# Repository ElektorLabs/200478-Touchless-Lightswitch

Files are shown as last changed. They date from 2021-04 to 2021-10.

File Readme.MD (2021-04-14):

# 200478 - Touchless Lightswitch

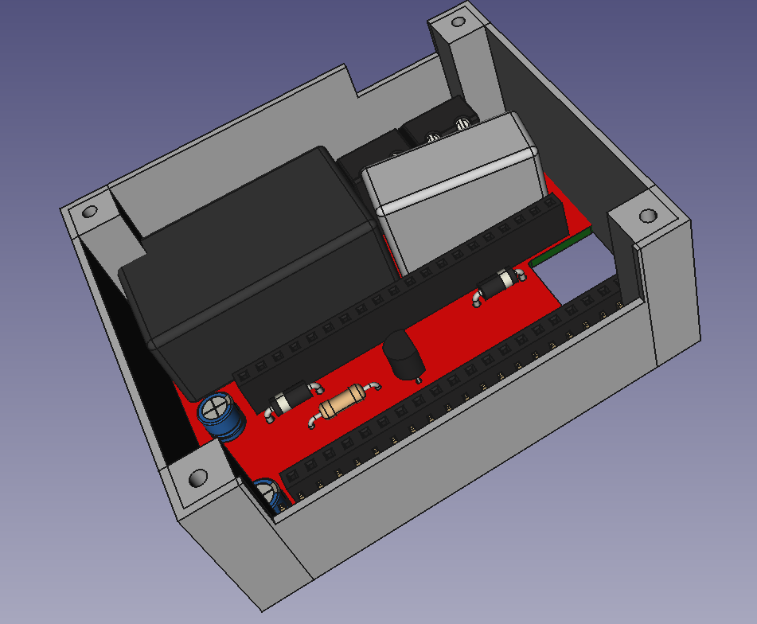
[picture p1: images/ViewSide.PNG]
3D Rendering of enclosure and pcb


## WARNING

This is work in progress and not finished. There may be leathal bugs inside the design. Use at your own risk

## Not working yet
```
- Webpage not included
- Size to large
- Mains supply not safe
```
## Description

This is the prototype of a touchless opperating lightswitch using the MGC3130 from Micorchip and an ESP32 as MCU
Code is done in PlatformIO and dependencys should be loaded automatically. 

A PCB done in KiCad and an Enclosure done in FreeCAD are also included. 

## Firmware installation

```bash
Download the code and import it into PlatformIO
```

## Contributing
Pull requests are welcome. For major changes, please open an issue first to discuss what you would like to change.

## Branches
Be aware that this project may use different branches and check out the one you like to use

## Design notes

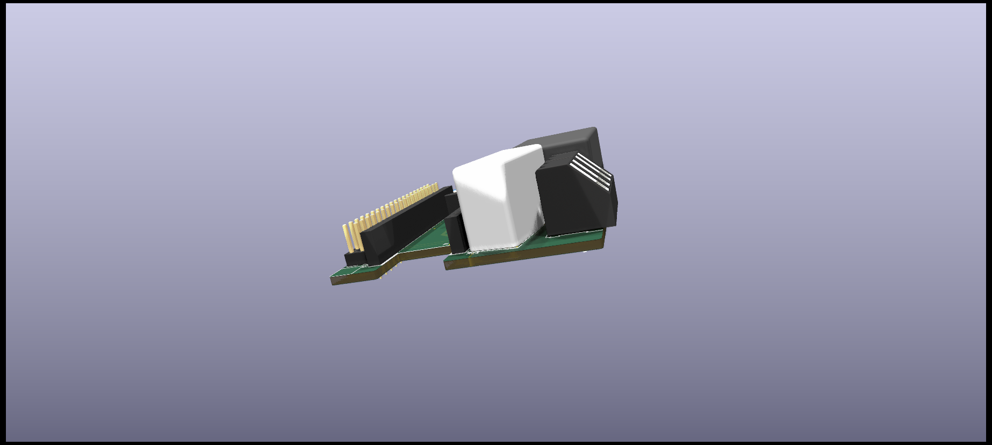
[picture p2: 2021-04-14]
images/TouchlessSwitch_PCB_Small.png

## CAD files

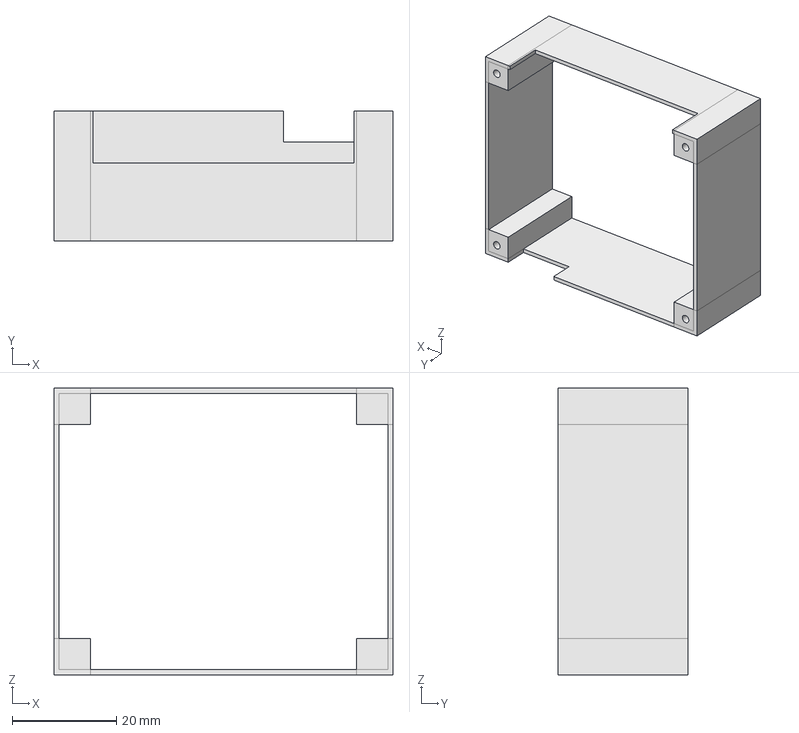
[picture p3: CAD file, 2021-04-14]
hardware/Enclosure/TouchSwitchEnclosure.step
65.0 x 25.0 x 55.0 mm

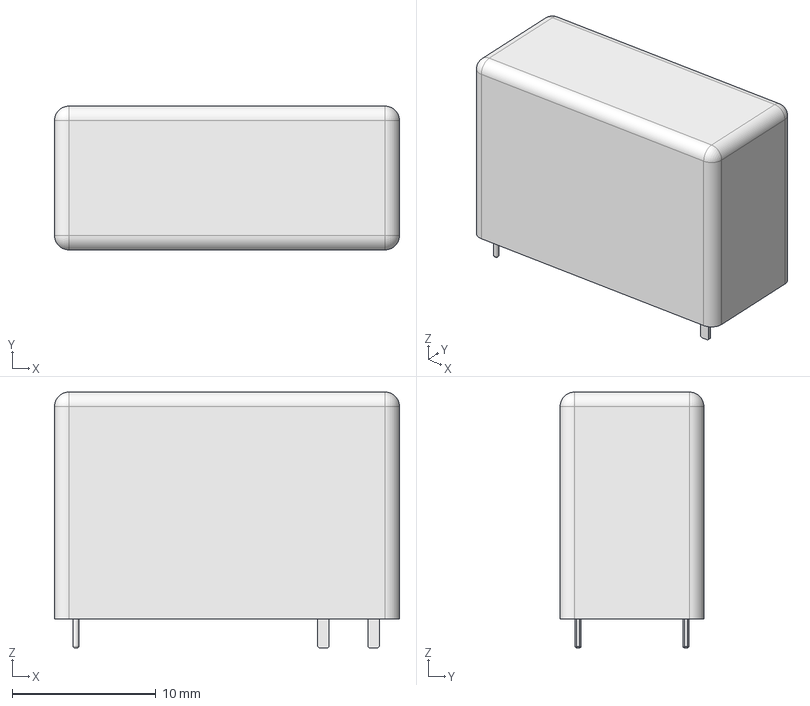
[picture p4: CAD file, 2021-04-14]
hardware/PCB/Touchless Switch/TouchlessSwitch/3D objects/ADW11HL.step
24.0 x 10.0 x 17.8 mm

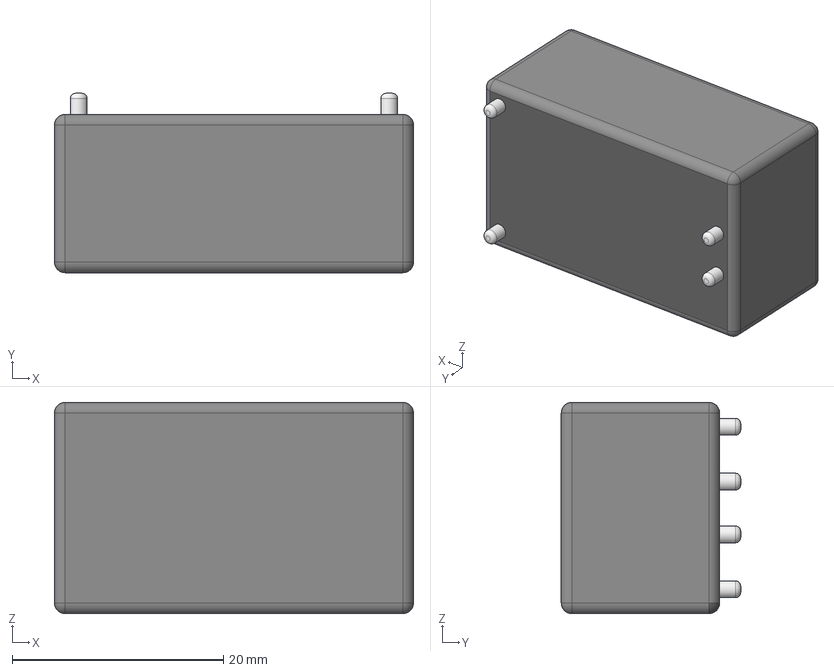
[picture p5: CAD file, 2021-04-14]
hardware/PCB/Touchless Switch/TouchlessSwitch/HKLinkACDC.step
34.0 x 17.0 x 20.0 mm

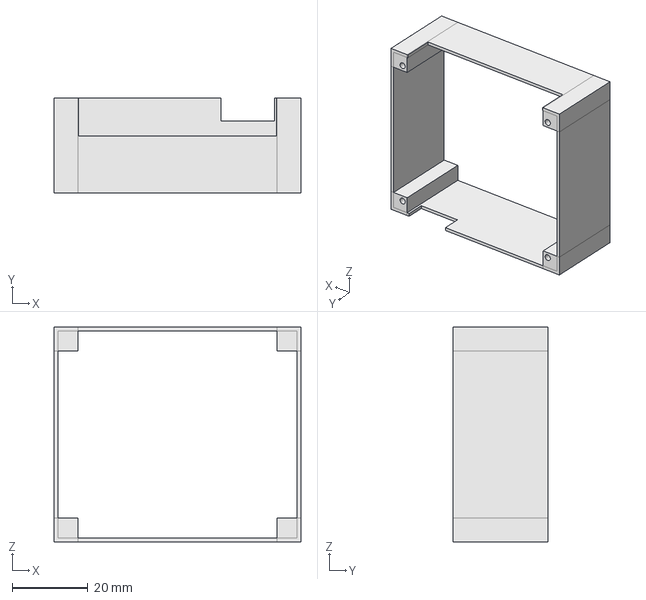
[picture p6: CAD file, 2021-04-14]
hardware/Enclosure/TouchlessTouchSwitch0_9.FCStd
65.0 x 25.0 x 56.5 mm

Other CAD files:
hardware/Enclosure/HiLinkACDC-PM01.FCStd
hardware/Enclosure/Relay_3D.FCStd
hardware/Enclosure/TouchSwitchEnclosure.stl

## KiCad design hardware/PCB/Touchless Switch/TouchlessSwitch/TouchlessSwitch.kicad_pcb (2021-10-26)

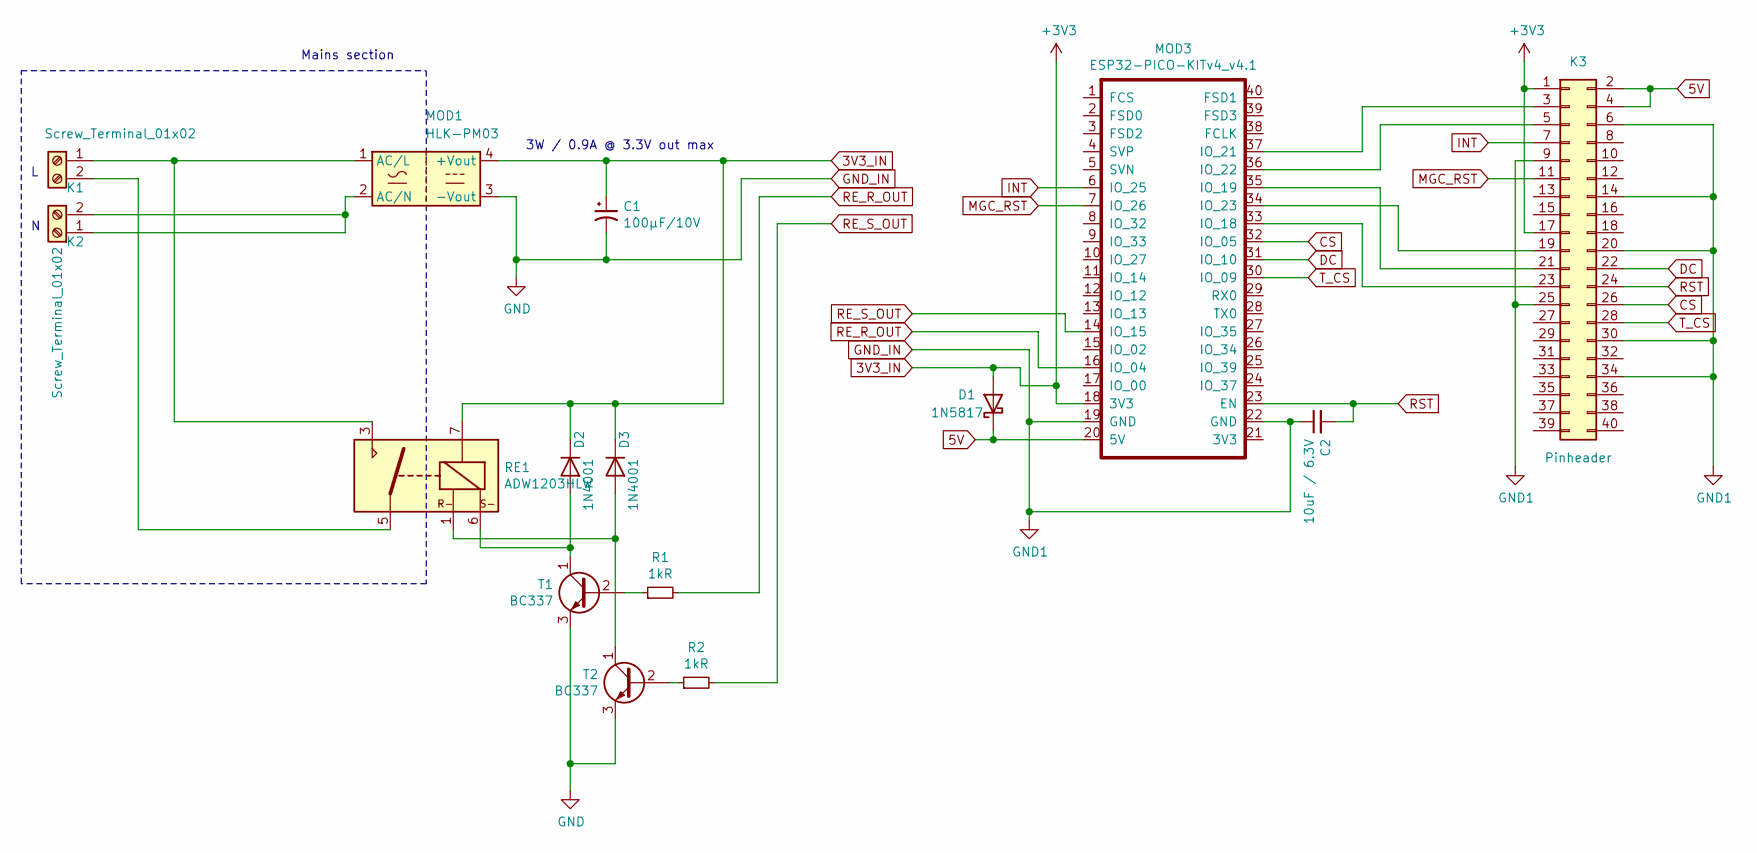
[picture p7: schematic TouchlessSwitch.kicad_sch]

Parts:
C1: 100µF/10V; CP_Radial_D5.0mm_P2.00mm
C2: 10uF / 6.3V; CP_Radial_D5.0mm_P2.00mm
D1: 1N5817; D_DO-41_SOD81_P7.62mm_Horizontal
D2, D3: 1N4001; D_DO-41_SOD81_P7.62mm_Horizontal
K1, K2: Screw_Terminal_01x02; TerminalBlock_Altech_AK300-2_P5.00mm
K3: Pinheader; PinHeader_2x20_P2.54mm_Vertical
MOD1: HLK-PM03; Converter_ACDC_HiLink_HLK-PMxx
MOD3: ESP32-PICO-KITv4_v4.1; DIP-40_W17.78mm_Socket
R1, R2: 1kR; R_Axial_DIN0207_L6.3mm_D2.5mm_P10.16mm_Horizontal
RE1: ADW1203HLW; Relay_1P1T_NO_10x24x18.8mm_Panasonic_ADW11xxxxW_THT
T1, T2: BC337; TO-92_Inline

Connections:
3V3_IN: C1.1, D1.2 (A), D2.1 (K), D3.1 (K), K3.1, K3.17, MOD1.4 (+Vout), MOD3.18 (3V3), RE1.7
5V: D1.1 (K), K3.2, K3.4, MOD3.20 (5V)
CS: K3.26, MOD3.32 (IO_05)
DC: K3.22, MOD3.31 (IO_10)
GND_IN: C1.2, C2.1, K3.6, K3.9, K3.14, K3.20, K3.25, K3.30, K3.34, MOD1.3 (-Vout), MOD3.19 (GND), MOD3.22 (GND), T1.3 (E), T2.3 (E)
INT: K3.7, MOD3.6 (IO_25)
MGC_RST: K3.11, MOD3.7 (IO_26)
unnamed: D2.2 (A), RE1.6, T1.1 (C)
unnamed: D3.2 (A), RE1.1, T2.1 (C)
unnamed: K1.1, MOD1.1 (AC/L), RE1.3
unnamed: K1.2, RE1.5
unnamed: K2.1, K2.2, MOD1.2 (AC/N)
unnamed: K3.3, MOD3.37 (IO_21)
unnamed: K3.5, MOD3.36 (IO_22)
unnamed: K3.19, MOD3.34 (IO_23)
unnamed: K3.21, MOD3.35 (IO_19)
unnamed: K3.23, MOD3.33 (IO_18)
unnamed: R1.1, T1.2 (B)
unnamed: R2.1, T2.2 (B)
RE_R_OUT: MOD3.16 (IO_04), R1.2
RE_S_OUT: MOD3.14 (IO_15), R2.2
RST: C2.2, K3.24, MOD3.23 (EN)
T_CS: K3.28, MOD3.30 (IO_09)

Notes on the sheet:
Mains section
3W / 0.9A @ 3.3V out max

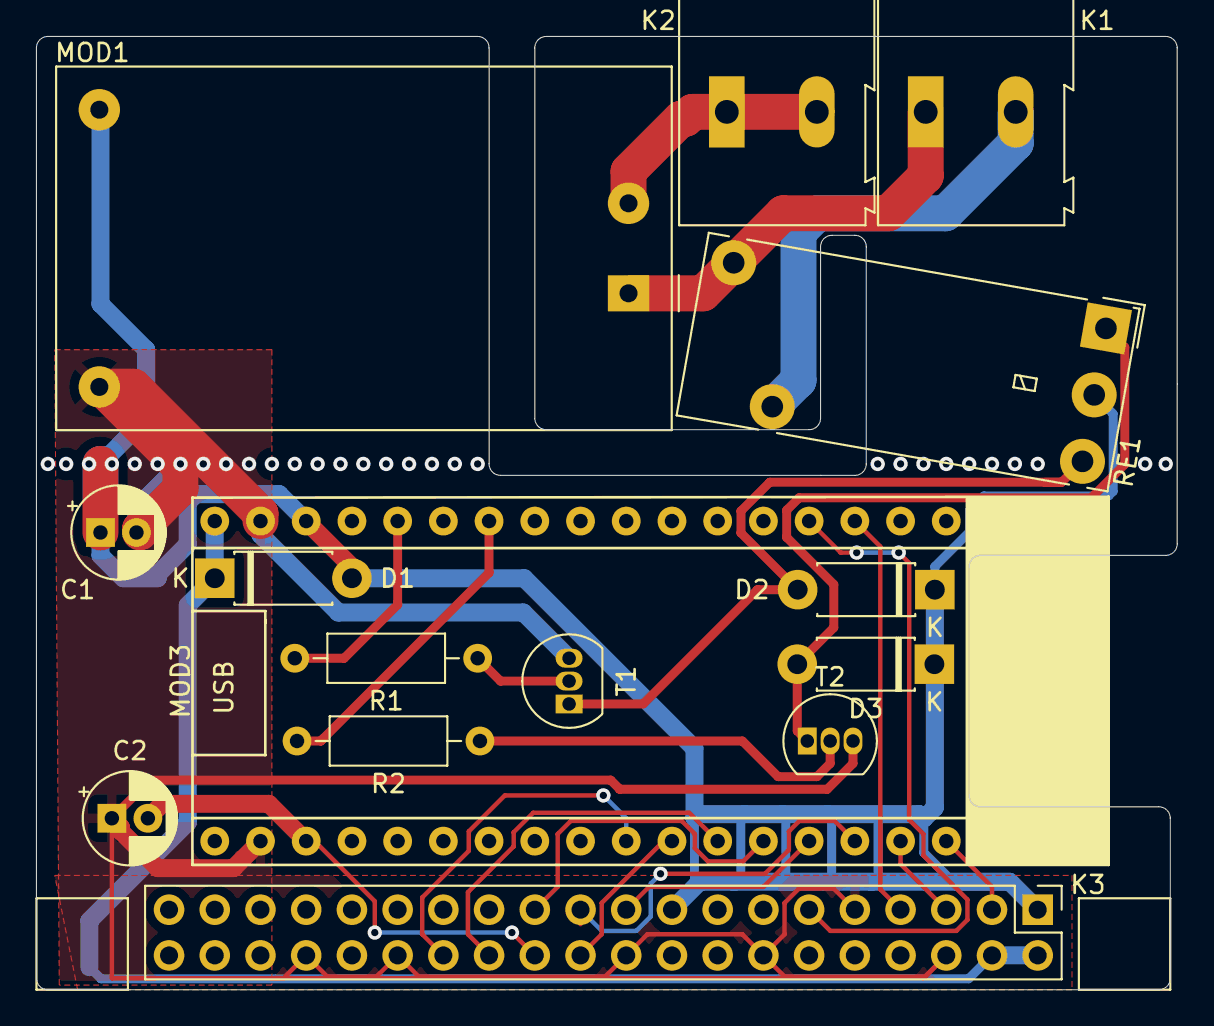
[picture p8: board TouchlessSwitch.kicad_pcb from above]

Board: 2 copper layers, 63.4 x 53.0 mm, 15 parts (0 on the bottom side), 23 nets.

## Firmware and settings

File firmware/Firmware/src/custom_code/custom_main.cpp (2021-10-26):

#include <Arduino.h>
#include <ESPmDNS.h>
#include <WiFiUdp.h>
#include <ArduinoJson.h>

#include "./../webserver_base.h"
#include "./../wifi_net.h"
#include "./../version.h"

#include "./../driver/touchinput.h"
#include "./../driver/relais.h"
#include "./../connector/MQTT/mqtt_connector.h"
#include "./web_api/webapi_mqtt_connector.h"
#include "./web_api/webapi_switch.h"
#include "custom_config.h"


#define RELAIS_PIN_SET 4
#define RELAIS_PIN_RESET 15


SemaphoreHandle_t RelaisStateChangeSem=NULL;

Relais relais;


void LightswitchStatchange( bool newstate );

void  custom_setup(){
    //Custom setup 
    #ifdef custom_serial_debug
        Serial.println("Touchdriver Init");
    #endif
    TouchInput_begin(25,26);
    #ifdef custom_serial_debug
        Serial.println("Relais init");
    #endif
    RelaisStateChangeSem = xSemaphoreCreateBinary();
    relais.begin(RELAIS_PIN_SET,RELAIS_PIN_RESET,false,false,RelaisStateChangeSem);
    MQTT_ConnectorStart();
    WEBAPI_MQTT_RegisterConnector();
    WEBAPI_Switch_RegisterConnector(&relais);



}

void  custom_loop(){
    StaticJsonDocument<200> doc;
    //Custom loop
    mqtt_msg_t* msg=NULL;
    msg=MQTT_GetReceivedMessageObj();
    if(msg!=NULL){
        //We need to read the message and expect a JSON object....
        DeserializationError error = deserializeJson(doc, msg->buffer,msg->msglen);
          if (error) {
            #ifdef custom_serial_debug
                Serial.print(F("deserializeJson() failed: "));
                Serial.println(error.f_str());
            #endif
          } else {
              bool state = doc["state"];
              if( false == state){
                  relais.off();
              } else {
                  relais.on();
              }
          }
        
        MQTT_ReturnReceivedMessage(msg);
  
    }
    if(true==xSemaphoreTake(RelaisStateChangeSem,0)){
        //State has chaned....
        LightswitchStatchange(relais.GetStatus());

    }

}

void LightswitchStatchange( bool newstate ){
    String output;
    StaticJsonDocument<16> doc;
    doc["state"] = newstate ;
    serializeJson(doc, output);
    MQTT_Send_Message(output.length(),(char*)(output.c_str()));
}

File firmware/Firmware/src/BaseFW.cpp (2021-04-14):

//****************************************************************************
// Firmware Base Version 0.1 - 06.04.2021
//
//****************************************************************************
#include <Arduino.h>
#include <ESPmDNS.h>
#include <WiFiUdp.h>
#include <ArduinoOTA.h>
#include "FS.h"
#include <Wire.h> 
#include "SPIFFS.h"
#include <Update.h>


#include "./wifi_net.h"
#include "./datastore.h"
#include "config.h"

#if __has_include("./custom_code/custom_main.h") 
  #include "./custom_code/custom_main.h"
#endif




/**************************************************************************************************
 *    Function      : setup_iopins
 *    Description   : This will enable the IO-Pins
 *    Input         : none 
 *    Output        : none
 *    Remarks       : none 
 **************************************************************************************************/
void setup_iopins( void ){
  
  pinMode(0,INPUT_PULLUP); //Boot Pin 
 
}


/**************************************************************************************************
 *    Function      : StartOTA
 *    Description   : This will prepare the OTA Service
 *    Input         : none 
 *    Output        : none
 *    Remarks       : none 
 **************************************************************************************************/
void StartOTA(){

#ifdef DEBUG_SERIAL_OTA
  Serial.println("Start OTA Service");
#endif
  ArduinoOTA
    .onStart([]() {
      String type;
      if (ArduinoOTA.getCommand() == U_FLASH)
        type = "sketch";
      else // U_SPIFFS
        type = "filesystem";

      // NOTE: if updating SPIFFS this would be the place to unmount SPIFFS using SPIFFS.end()
      #ifdef DEBUG_SERIAL_OTA
        Serial.println("Start updating " + type);
      #endif
    })
    .onEnd([]() {
      #ifdef DEBUG_SERIAL_OTA
        Serial.println("\nEnd");
      #endif
    })
    .onProgress([](unsigned int progress, unsigned int total) {
      #ifdef DEBUG_SERIAL_OTA
        Serial.printf("Progress: %u%%\r", (progress / (total / 100)));
      #endif
    })
    .onError([](ota_error_t error) {
      #ifdef DEBUG_SERIAL_OTA
        Serial.printf("Error[%u]: ", error);
        if (error == OTA_AUTH_ERROR) Serial.println("Auth Failed");
        else if (error == OTA_BEGIN_ERROR) Serial.println("Begin Failed");
        else if (error == OTA_CONNECT_ERROR) Serial.println("Connect Failed");
        else if (error == OTA_RECEIVE_ERROR) Serial.println("Receive Failed");
        else if (error == OTA_END_ERROR) Serial.println("End Failed");
      #endif
    });

  ArduinoOTA.begin();

}


void  __attribute__((weak)) custom_setup(){

}

void  __attribute__((weak))custom_loop(){

}

/**************************************************************************************************
 *    Function      : setup
 *    Description   : This will onyl run once after boot
 *    Input         : none 
 *    Output        : none
 *    Remarks       : none 
 **************************************************************************************************/
void setup() {
  Serial.begin(115200);
  SPIFFS.begin(); /* This can be called multiple times, allready mounted it will just return */
  datastoresetup();
  
  setup_iopins();

  //We also need to mount the SPIFFS
  if(!SPIFFS.begin(true)){
     #ifdef DEBUG_SERIAL
      Serial.println("An Error has occurred while mounting SPIFFS");
     #endif
  }
  //Next step is to setup wifi and check if the configured AP is in range
  WiFiClientEnable(true); //Force WiFi on 
  WiFiForceAP(false); //Diable Force AP
  #ifdef DEBUG_SERIAL
    Serial.println("Continue boot");
  #endif
  

  RegisterWiFiConnectedCB(StartOTA);
  #ifdef DEBUG_SERIAL
    Serial.println("Initialize WiFi");
  #endif
 //If the button is pressed during start we will go to the AP Mode
    if(0 != digitalRead(0) ){
      initWiFi( false, false );
    } else {
      #ifdef DEBUG_SERIAL
        Serial.println("Force System to AP");
      #endif
      initWiFi( false , true );   
    }
  custom_setup();
}


/**************************************************************************************************
 *    Function      : loop
 *    Description   : Main Loop
 *    Input         : none 
 *    Output        : none
 *    Remarks       : none 
 **************************************************************************************************/
void loop() {
  /* This will be executed in the arduino main loop */
  ArduinoOTA.handle();
  NetworkLoopTask();
  custom_loop();
}

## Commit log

2021-10-26 Update for latching relay
2021-10-26 PCB Files Update for latching relay
    [Combinded_Switch.FCStd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]
